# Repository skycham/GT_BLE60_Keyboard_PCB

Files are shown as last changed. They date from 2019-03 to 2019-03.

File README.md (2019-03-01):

# GT_BLE60_Keyboard_PCB
A 60% bluetooth keyboard PCB by Kicad, Schematic fork of https://github.com/Lotlab/BLE60-keyboard  
一个采用Kicad设计制作的60%蓝牙键盘PCB，原理图参考Lotlab的蓝牙键盘，并基于GH60制作。

**已经验证完成，可以直接打板制作**

using nRF51822 and CH554(or CH552).  
使用NRF51822 与 CH554（或者CH552）芯片

Firmware Source Code/固件源码: [nrf51822-keyboard](https://github.com/genokolar/nrf51822-keyboard/tree/GT-BLE60)

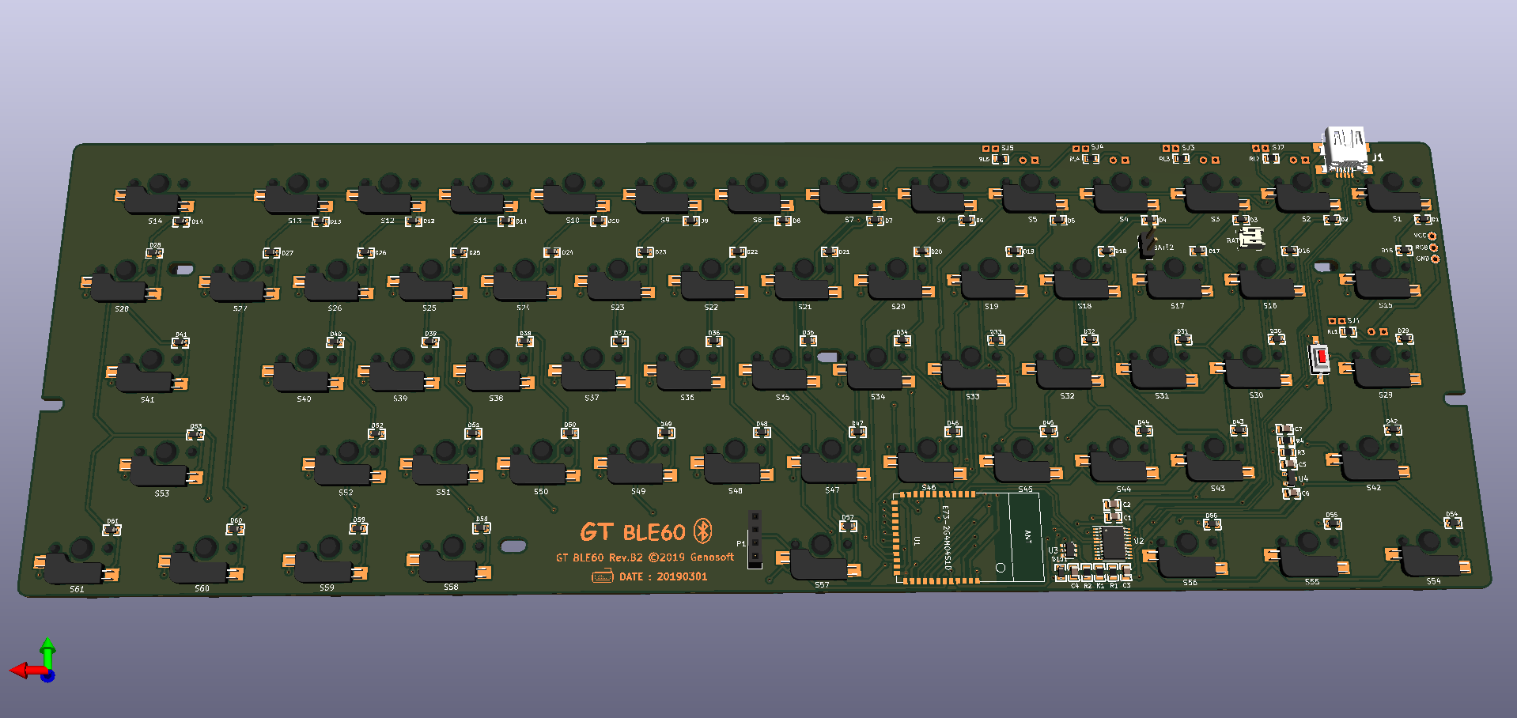
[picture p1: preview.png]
pad图片


License: CC-BY-SA

More description/详细信息在此查看：[http://genokolar.github.io/blog/201903](http://genokolar.github.io/blog/201903)

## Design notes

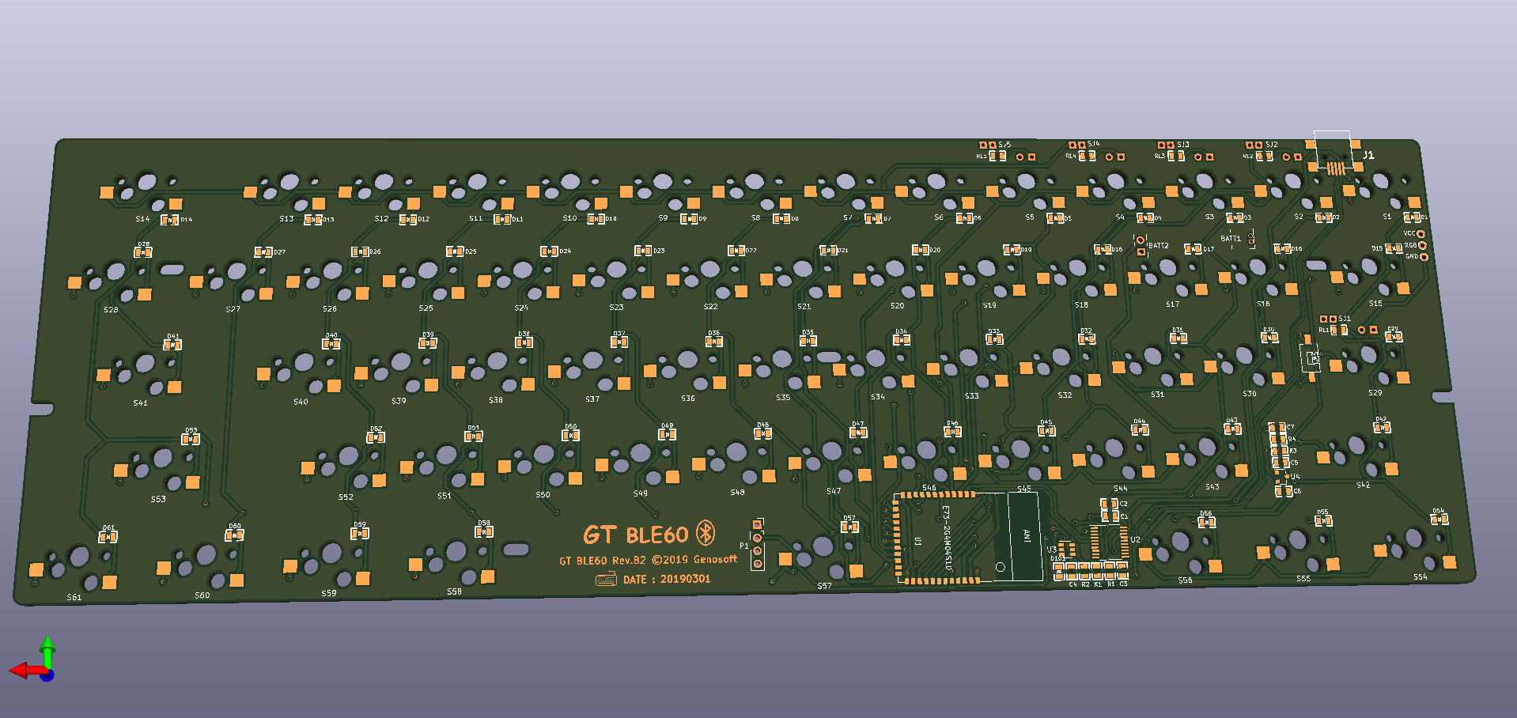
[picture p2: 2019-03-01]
preview4.png

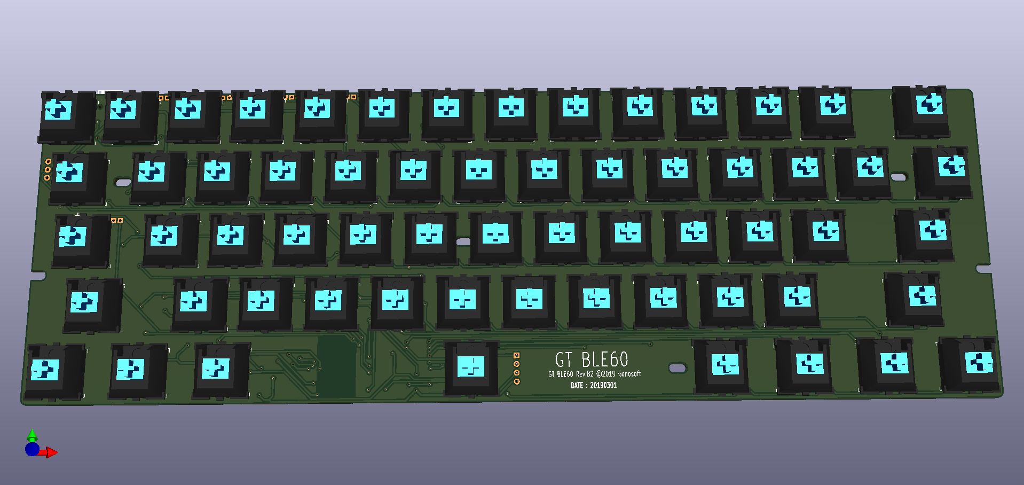
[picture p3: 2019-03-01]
preview2.png

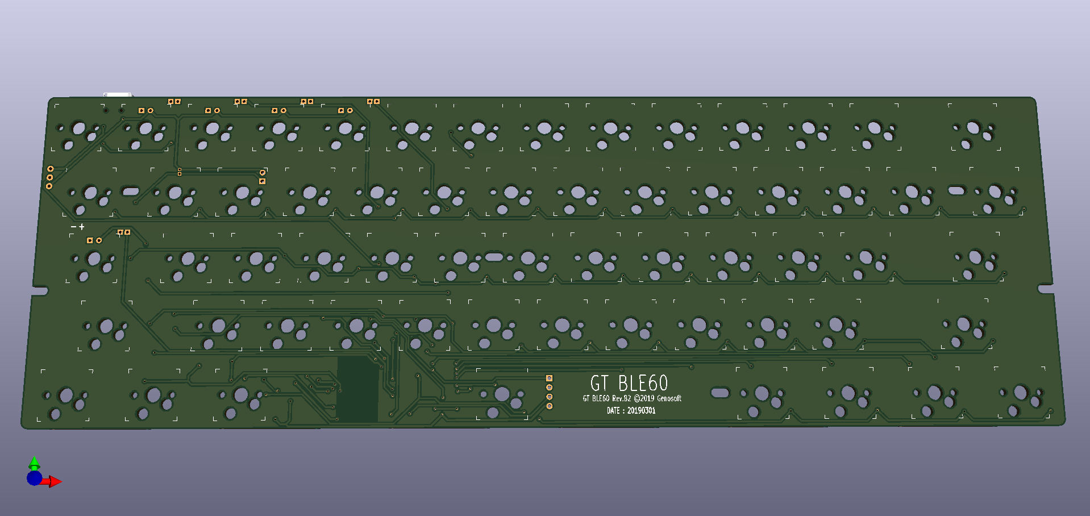
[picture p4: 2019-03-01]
preview3.png

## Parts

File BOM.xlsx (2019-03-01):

Id | 代号 | 封装 | 数量 | 名称 | 备注说明
1 | BATT1 | PinHeader_2x1.25mm | 1 | PinHeader_2x1.25mm | 锂电池接口
2 | C1,C2 | 0805C | 2 | 0.1uF
3 | C3 | 0805C | 1 | NC/47pF | 可不用焊接
4 | C4,C5,C6 | 0805C | 3 | 1uF
5 | C7 | 0805C | 1 | 10nF
6 | D101 | 0805D | 1 | SS14 | 肖特基二极管，锂电池芯片TP4057用
7 | D1-D61 | 0805D | 61 | 1N4148 | 全键防冲二极管，焊接注意方向
8 | J1 | 67503 | 1 | USBMINI_B05 | MINI USB接口
10 | K1 | 0805R | 1 | DownloadKey | 不用焊接元件，用于短接进入CH552的刷写模式
11 | LED1-LED6 | MX1A-led | 6 | LED | 指示灯（除CAPS外属于预留）
12 | R1 | 0805R | 1 | 10K | 接CH552的3.3V电源引脚，以便短接刷机
13 | R2 | 0805R | 1 | 4.7K | 建议2K-5K 之间，其中2K时充电电流为400ma，5K时充电电流为200ma，详细内容参看TP4057技术手册
14 | R3 | 0805R | 1 | 10M | 精度重要，以此为参考检测锂电池电量
15 | R4 | 0805R | 1 | 2.2M | 精度重要，以此为参考检测锂电池电量
16 | RL1-RL5 | 0805R | 5 | 300R | 指示灯灯阻
17 | S1-S61 | Kailh-3d-noled | 61 | MX1A | 机械键盘轴体
18 | U1 | E73-2G4M04S1D | 1 | E73-2G4M04S1D | 蓝牙主控模块
19 | U2 | CH552T | 1 | CH552T | USB芯片
20 | U3 | SOT-23-6 | 1 | TP4057 | 锂电池充电芯片
21 | U4 | SOT-23 | 1 | XC6206P30 | 3.3V稳压，用于主控供电
22 | SW1 | Switch | 1 | Bootloader Button | 进入刷机模式的按钮

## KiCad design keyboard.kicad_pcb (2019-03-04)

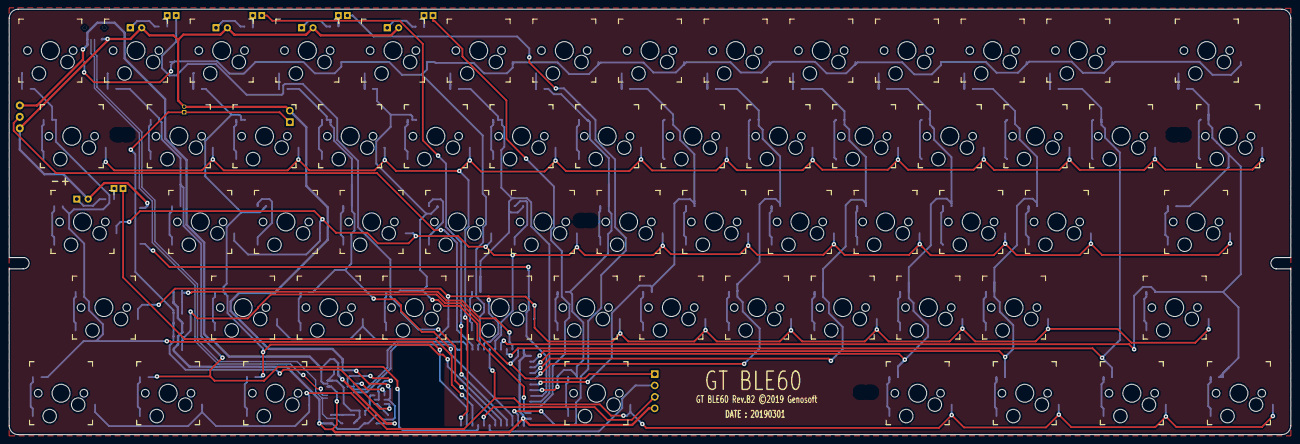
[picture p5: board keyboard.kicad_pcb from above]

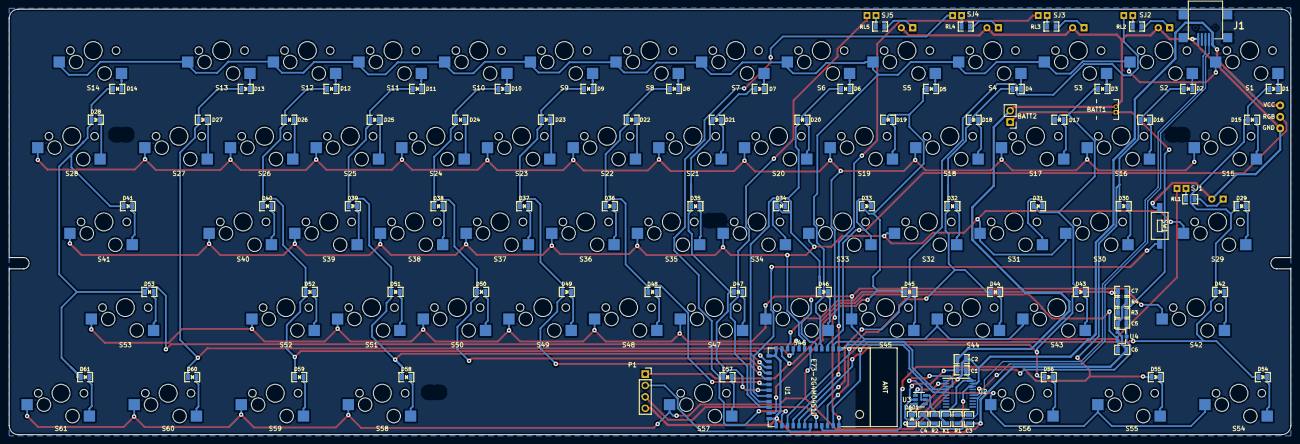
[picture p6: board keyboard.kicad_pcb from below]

Board: 2 copper layers, 285.0 x 94.6 mm, 168 parts (98 on the bottom side), 114 nets.

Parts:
BATT1: PinHeader_2x1.25mm
BATT2: BATT; PinHeader_1x02_P2.54mm_Vertical
C1, C2: 0.1uF; 0805C
C3: NC/47pF; 0805C
C4, C5, C6: 1uF; 0805C
C7: 10nF; 0805C
D1, D2, D3, D4, D5, D6, D7, D8, D9, D10, D11, D12, D13, D14, D15, D16, D17, D18, D19, D20, D21, D22, D23, D24, D25, D26, D27, D28, D29, D30, D31, D32, D33, D34, D35, D36, D37, D38, D39, D40, D41, D42, D43, D44, D45, D46, D47, D48, D49, D50, D51, D52, D53, D54, D55, D56, D57, D58, D59, D60, D61: 1N4148; 0805D
D101: SS14; 0805D
GND: CONN_1; pad
HOLE1, HOLE2, HOLE3, HOLE4: VAL; PKRH-2
J1: USBMINI_B05; 67503
K1: DownloadKey; 0805R
LED1, LED2, LED3, LED4, LED5: LED; MX1A-led
LOGO1: LOGO; GTBLE60
LOGO2: LOGO; Bluetooth
P1: SWD; PinSocket_1x04_P2.54mm_Vertical
R1: 10K; 0805R
R2: 4.7K; 0805R
R3: 10M; 0805R
R4: 2.2M; 0805R
RGB: CONN_1; pad
RL1, RL2, RL3, RL4, RL5: 300; 0805R
S1, S2, S3, S4, S5, S6, S7, S8, S9, S10, S11, S12, S13, S14, S15, S16, S17, S18, S19, S20, S21, S22, S23, S24, S25, S26, S27, S28, S29, S30, S31, S32, S33, S34, S35, S36, S37, S38, S39, S40, S41, S42, S43, S44, S45, S46, S47, S48, S49, S50, S51, S52, S53, S54, S55, S56, S57, S58, S59, S60, S61: MX1A; Kailh-3d-noled
SJ1, SJ2, SJ3, SJ4, SJ5: SOLDER_JUMPER; 2_Pin_Jumper
SW1: Bootloader Button; Switch
U1: E73-2G4M04S1D
U2: CH552T
U3: TP4057; SOT-23-6
U4: XC6206P30; SOT-23
VCC: CONN_1; pad

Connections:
3V3: C6.1, P1.1, U1.11, U4.2
/DFU: SW1.2, U1.20
/RGB: RGB.1, U1.3
/caps_led: SJ1.1, U1.34
/col1: D1.1, D15.1, D29.1, D42.1, D54.1, U1.35
/col2: D2.1, D16.1, D30.1, D55.1, U1.33
/col3: D3.1, D17.1, D31.1, D43.1, D56.1, U1.29
/col4: D4.1, D18.1, D32.1, D44.1, U1.27
/col5: D5.1, D19.1, D33.1, D45.1, U1.23
/col6: D6.1, D20.1, D34.1, D46.1, U1.21
/col7: D7.1, D21.1, D35.1, D47.1, D57.1, U1.19
/col8: D8.1, D22.1, D36.1, D48.1, U1.18
/col9: D9.1, D23.1, D37.1, D49.1, U1.17
/col10: D10.1, D24.1, D38.1, D50.1, U1.16
/col11: D11.1, D25.1, D39.1, D51.1, D58.1, U1.15
/col12: D12.1, D26.1, D40.1, D52.1, D59.1, U1.14
/col13: D13.1, D27.1, D60.1, U1.9
/col14: D14.1, D28.1, D41.1, D53.1, D61.1, U1.8
/led1: SJ2.1, U1.30
/led2: SJ3.1, U1.28
/led3: SJ4.1, U1.26
/led4: SJ5.1, U1.22
/row1: S1.1, S2.1, S3.1, S4.1, S5.1, S6.1, S7.1, S8.1, S9.1, S10.1, S11.1, S12.1, S13.1, S14.1, U1.4
/row2: S15.1, S16.1, S17.1, S18.1, S19.1, S20.1, S21.1, S22.1, S23.1, S24.1, S25.1, S26.1, S27.1, S28.1, U1.36
/row3: S29.1, S30.1, S31.1, S32.1, S33.1, S34.1, S35.1, S36.1, S37.1, S38.1, S39.1, S40.1, S41.1, U1.7
/row4: S42.1, S43.1, S44.1, S45.1, S46.1, S47.1, S48.1, S49.1, S50.1, S51.1, S52.1, S53.1, U1.5
/row5: S54.1, S55.1, S56.1, S57.1, S58.1, S59.1, S60.1, S61.1, U1.6
ADC1: C7.1, R3.2, R4.1, U1.10
BATT: BATT1.1, BATT2.1, C5.1, R3.1, U3.3, U4.3
CHRG: U2.2, U3.1
DCLK: P1.3, U1.32
DIO: P1.2, U1.31
GND: BATT1.2, BATT2.2, C1.2, C2.2, C3.2, C4.2, C5.2, C6.2, C7.2, GND.1, J1.5, LED1.1, LED2.1, LED3.1, LED4.1, LED5.1, P1.4, R2.2, R4.2, SW1.1, U1.12, U1.13, U1.24, U1.25, U2.18, U3.2, U4.1
unnamed: C3.1, K1.1, R1.1
unnamed: D1.2, S1.2
unnamed: D2.2, S2.2
unnamed: D3.2, S3.2
unnamed: D4.2, S4.2
unnamed: D5.2, S5.2
unnamed: D6.2, S6.2
unnamed: D7.2, S7.2
unnamed: D8.2, S8.2
unnamed: D9.2, S9.2
unnamed: D10.2, S10.2
unnamed: D11.2, S11.2
unnamed: D12.2, S12.2
unnamed: D13.2, S13.2
unnamed: D14.2, S14.2
unnamed: D15.2, S15.2
unnamed: D16.2, S16.2
unnamed: D17.2, S17.2
unnamed: D18.2, S18.2
unnamed: D19.2, S19.2
unnamed: D20.2, S20.2
unnamed: D21.2, S21.2
unnamed: D22.2, S22.2
unnamed: D23.2, S23.2
unnamed: D24.2, S24.2
unnamed: D25.2, S25.2
unnamed: D26.2, S26.2
unnamed: D27.2, S27.2
unnamed: D28.2, S28.2
unnamed: D29.2, S29.2
unnamed: D30.2, S30.2
unnamed: D31.2, S31.2
unnamed: D32.2, S32.2
unnamed: D33.2, S33.2
unnamed: D34.2, S34.2
unnamed: D35.2, S35.2
unnamed: D36.2, S36.2
unnamed: D37.2, S37.2
unnamed: D38.2, S38.2
unnamed: D39.2, S39.2
unnamed: D40.2, S40.2
unnamed: D41.2, S41.2
unnamed: D42.2, S42.2
unnamed: D43.2, S43.2
unnamed: D44.2, S44.2
unnamed: D45.2, S45.2
unnamed: D46.2, S46.2
unnamed: D47.2, S47.2
unnamed: D48.2, S48.2
unnamed: D49.2, S49.2
unnamed: D50.2, S50.2
unnamed: D51.2, S51.2
unnamed: D52.2, S52.2
unnamed: D53.2, S53.2
unnamed: D54.2, S54.2
unnamed: D55.2, S55.2
unnamed: D56.2, S56.2
unnamed: D57.2, S57.2
unnamed: D58.2, S58.2
unnamed: D59.2, S59.2
unnamed: D60.2, S60.2
unnamed: D61.2, S61.2
unnamed: D101.2, U3.4
unnamed: LED1.2, RL1.2
unnamed: LED2.2, RL2.1
unnamed: LED3.2, RL3.1
unnamed: LED4.2, RL4.1
unnamed: LED5.2, RL5.1
unnamed: R2.1, U3.6
unnamed: RL1.1, SJ1.2
unnamed: RL2.2, SJ2.2
unnamed: RL3.2, SJ3.2
unnamed: RL4.2, SJ4.2
unnamed: RL5.2, SJ5.2
RXD: U1.2, U2.4
STBY: U2.3, U3.5
TXD: U1.1, U2.5
UD+: J1.3, R1.2, U2.14
UD-: J1.2, U2.15
V33: C1.1, K1.2, U2.20
VCC: C2.1, C4.1, D101.1, J1.1, U2.19, VCC.1

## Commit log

2019-03-01 修正原理图两处错误，添加Bootloader按钮
    版本设定为B2版本，修正了原理图的两处错误，添加了Bootloadler按钮便于进入DFU刷机模式。
    [BOM.xlsx, keyboard.kicad_pcb, keyboard.sch]
2019-03-04 添加SWD接口丝印
    [keyboard.kicad_pcb]

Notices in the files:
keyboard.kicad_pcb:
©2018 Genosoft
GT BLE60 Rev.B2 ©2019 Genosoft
